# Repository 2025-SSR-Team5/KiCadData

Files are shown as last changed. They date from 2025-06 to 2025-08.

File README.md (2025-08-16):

# KiCadData

## Control Circuit<br>
- A面<br>
<br>

- B面<br>


連結した図
<br>

## Emergency Circuit<br>
動作電圧：7.8V以上（実測値）

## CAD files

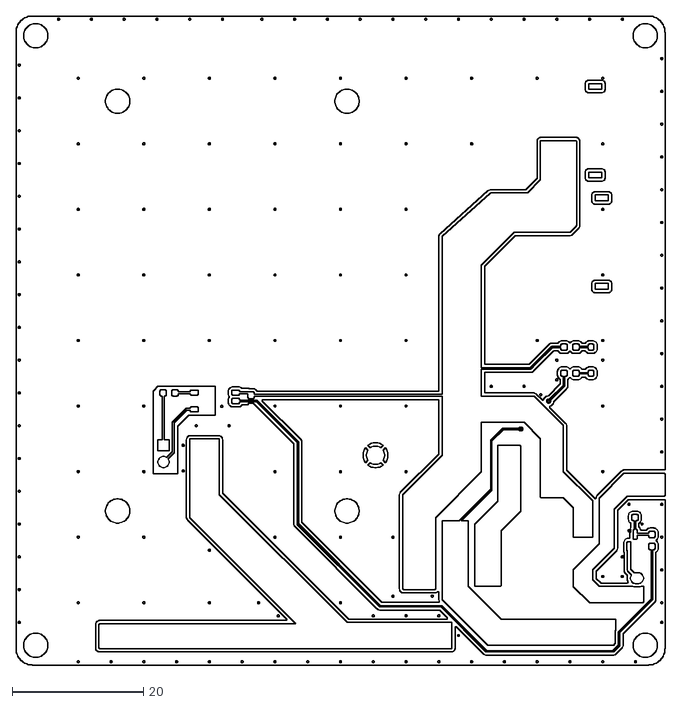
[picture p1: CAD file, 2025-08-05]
maincircuit/Emergency-F_Cu.dxf
99.0 x 99.0

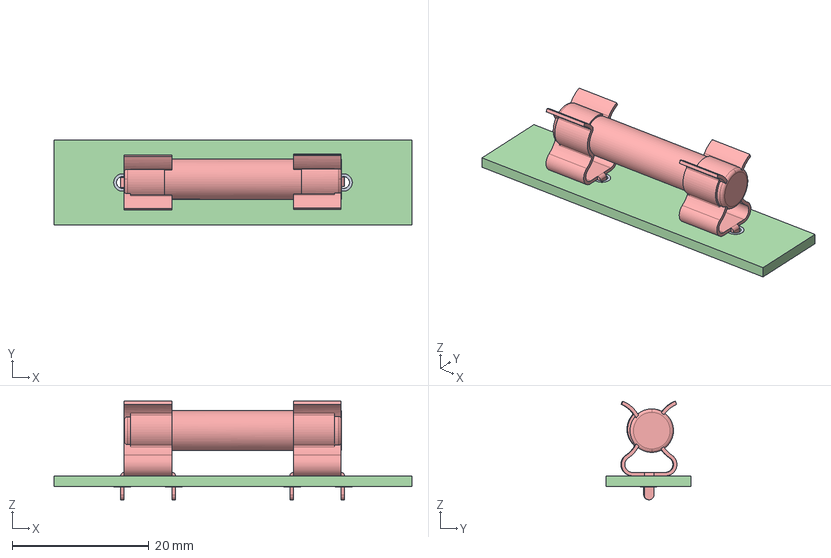
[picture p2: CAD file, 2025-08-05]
maincircuit/FreeCadData/FUC-04.FCStd
52.3 x 12.4 x 14.4 mm
topPads001
btmPads001
TH-Drills001
PCB001
FUC-006

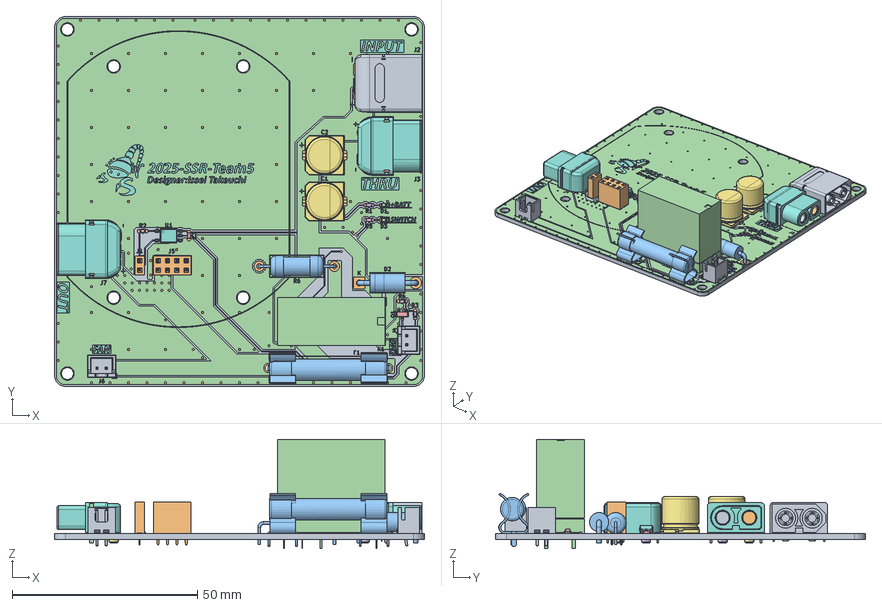
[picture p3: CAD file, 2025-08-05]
maincircuit/FreeCadData/基板外形/Emergency_完成版.FCStd
100.0 x 100.0 x 29.5 mm
Pcb_5d9a
topPads_5d9a
topTracks_5d9a
topZones_5d9a
botPads_5d9a
botTracks_5d9a
botZones_5d9a
topSilks_7ed9
J2_XT60PW-M_b9f98f7f5a08[2]
J1_PinSocket_1x02_P2.54mm_Vertical_96c703c1ea02
F1_FUC-006_d50f9b82165b
XT60PW_F x 2
XT60PW_F001 x 2
XT60PW_F002 x 2
XT60PW_F003 x 2
XT60PW_F004 x 2
XT60PW_F005 x 2
XT60PW_F006 x 2
D2_D_DO-201AD_P15.24mm_Horizontal_769b02e1d70d
D3_LED_0603_1608Metric_7a1c755dfa72 x 2
Q1_SOT-23_4aa83119404f
R1_R_0603_1608Metric_e639d62fb8c0 x 5
C2_CP_Elec_10x10_c9efb6612453 x 2
U1_SO-5-6_4.55x3.7mm_P1.27mm_6e65fe9860de
J4_JST_B2B_XH_A_65221954baed x 2
J5_PinSocket_2x04_P2.54mm_Vertical_8e1d09d268e3
R6_R_Axial_DIN0614_L143mm_D57mm_P2032mm_Horizontal_5dc615bd2039
K1_G2R_1_E_94cef88badf6
C3_C_0603_1608Metric_b537dff13701

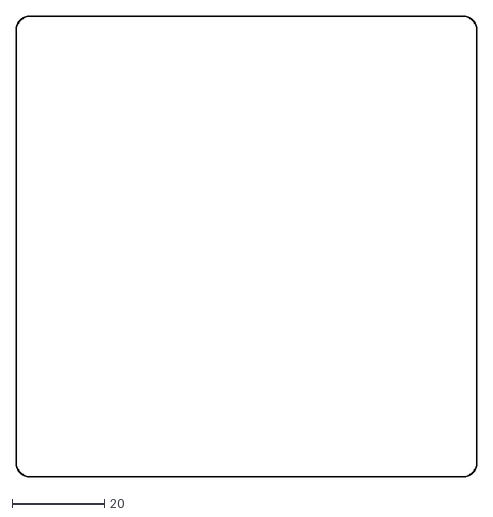
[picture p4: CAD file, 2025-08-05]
maincircuit/Emergency-Edge_Cuts.dxf
100.0 x 100.0

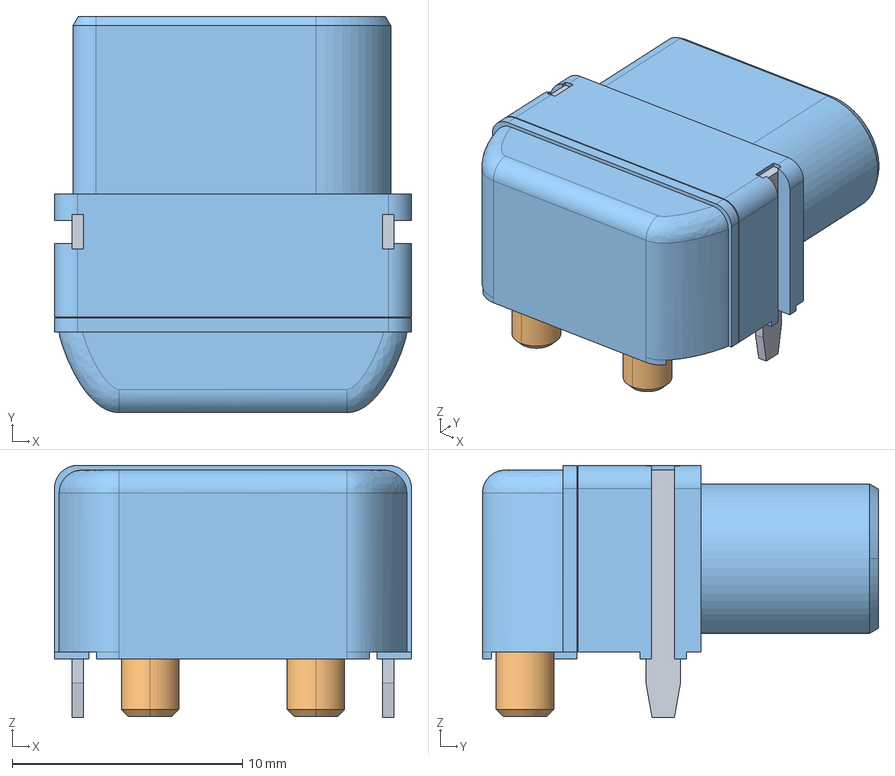
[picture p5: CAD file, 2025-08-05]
maincircuit/FreeCadData/XT60PW_F_cp001.step
15.5 x 17.2 x 10.9 mm

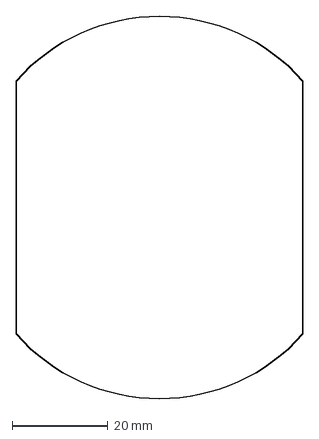
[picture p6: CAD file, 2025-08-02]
maincircuit/FreeCadData/基板外形/ControlCircuit.dxf
60.0 x 80.0 mm

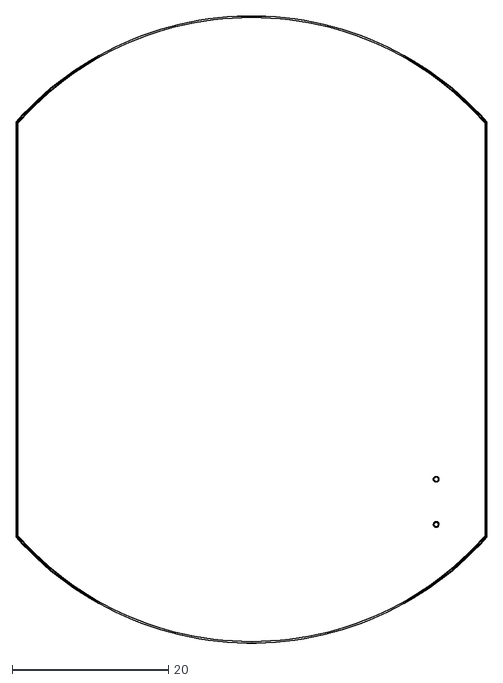
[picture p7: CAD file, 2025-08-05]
maincircuit/ControlCircuit-Edge_Cuts.dxf
60.2 x 80.2

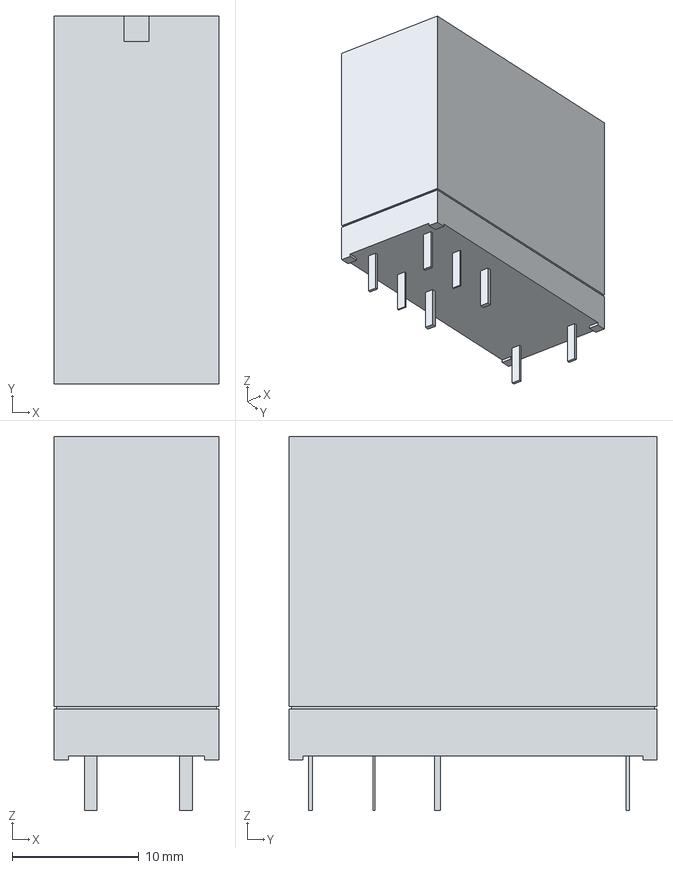
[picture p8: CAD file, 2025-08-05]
maincircuit/FreeCadData/G2R_1_E.step
13.0 x 29.0 x 29.5 mm

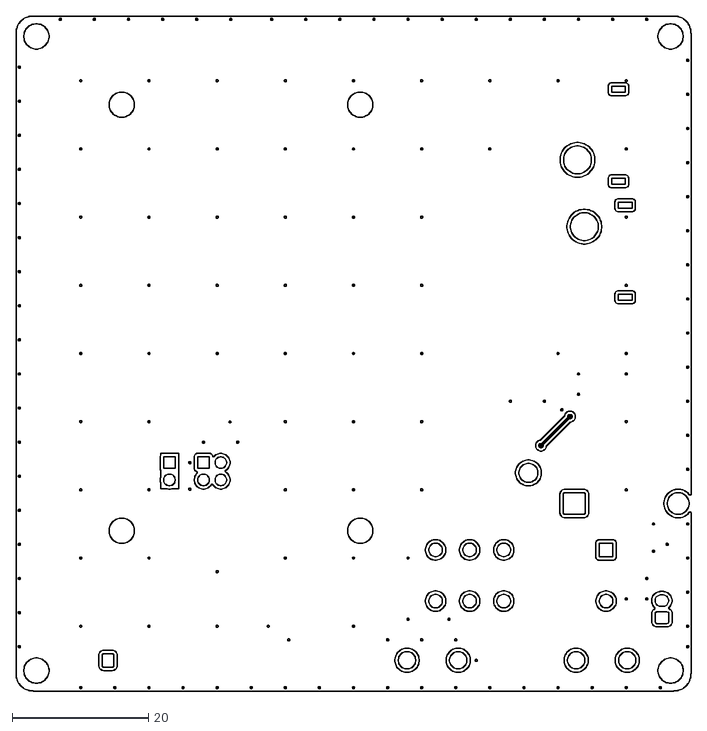
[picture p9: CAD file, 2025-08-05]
maincircuit/Emergency-B_Cu.dxf
99.0 x 99.0

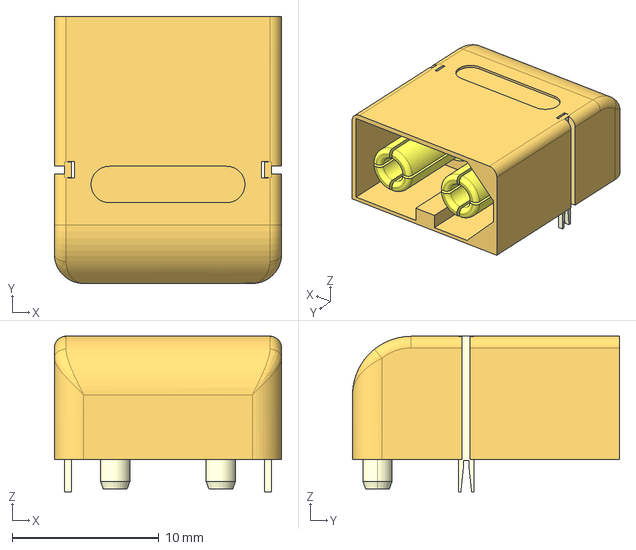
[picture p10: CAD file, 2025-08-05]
maincircuit/FreeCadData/XT60PW-M.step
15.5 x 18.2 x 10.6 mm

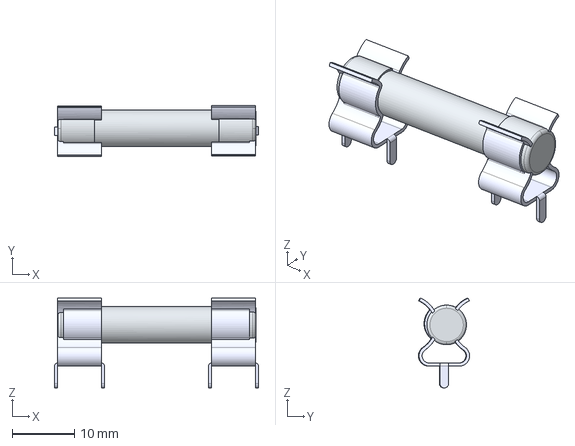
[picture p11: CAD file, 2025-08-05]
maincircuit/FreeCadData/FUC-006.step
32.7 x 8.20 x 14.4 mm

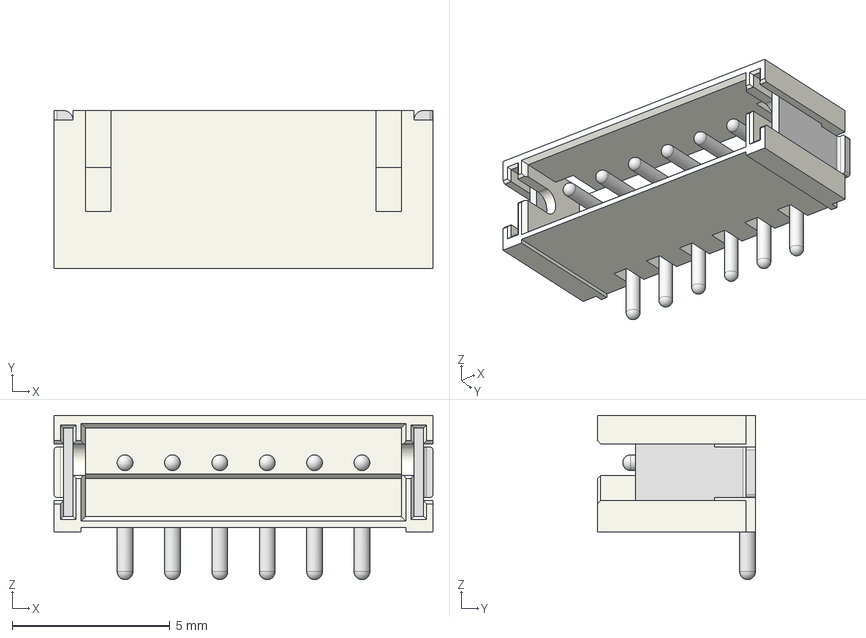
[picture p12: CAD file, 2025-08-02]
maincircuit/FreeCadData/ZH_Connector_SMT_Top.step
12.0 x 5.00 x 5.20 mm

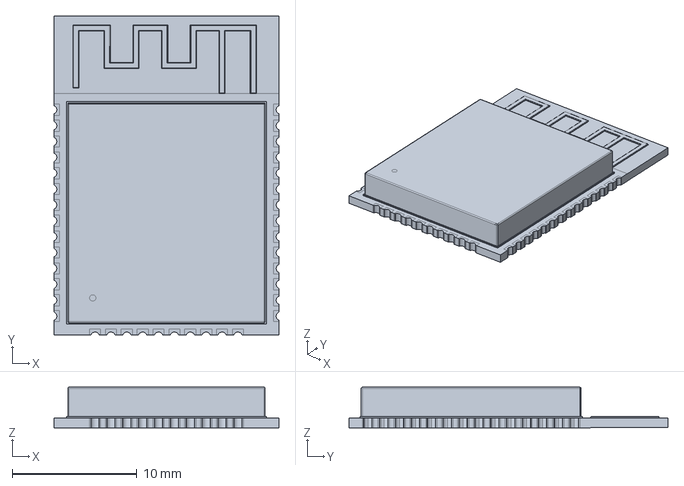
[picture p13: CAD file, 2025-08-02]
maincircuit/FreeCadData/ESP32-WROOM-32.step
18.0 x 25.5 x 3.25 mm

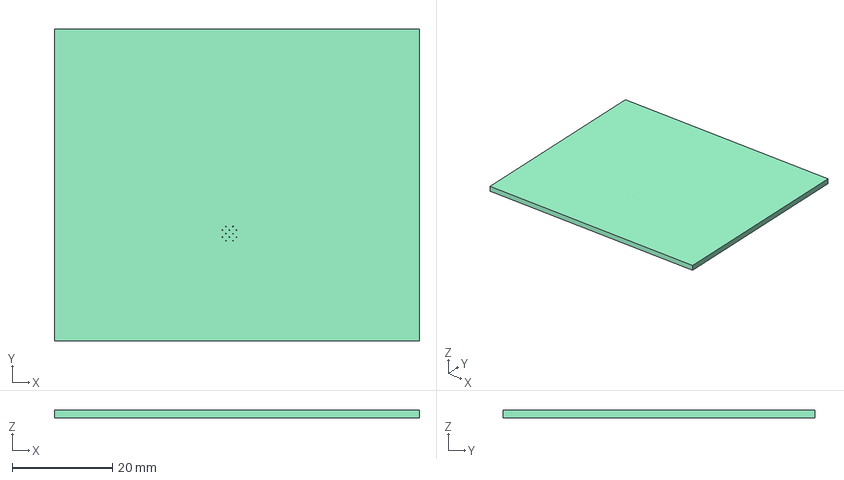
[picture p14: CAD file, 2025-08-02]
maincircuit/FreeCadData/PCB.step
72.8 x 62.3 x 1.58 mm

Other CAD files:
maincircuit/FreeCadData/XT60PW_F.step
maincircuit/FreeCadData/ESP32.FCStd
maincircuit/FreeCadData/MA10EB045.stp
maincircuit/FreeCadData/ZH_B6B.FCStd
maincircuit/ControlCircuit-B_Silkscreen.dxf
maincircuit/ControlCircuit-F_Silkscreen.dxf
maincircuit/Emergency-B_Mask.dxf
maincircuit/Emergency-B_Paste.dxf
maincircuit/Emergency-B_Silkscreen.dxf
maincircuit/Emergency-F_Mask.dxf
maincircuit/Emergency-F_Paste.dxf
maincircuit/Emergency-F_Silkscreen.dxf
maincircuit/FreeCadData/10132797-017100LF.FCStd
maincircuit/FreeCadData/10132797-017100LF.step
maincircuit/FreeCadData/10132798-012100LF.FCStd
maincircuit/FreeCadData/10132798-012100LF_ASM.step
maincircuit/FreeCadData/2SC3325.FCStd
maincircuit/FreeCadData/2SC3325.step
maincircuit/FreeCadData/5077CR-16SMC2-BK-TR019.FCStd
maincircuit/FreeCadData/5077CR-16SMC2-BK-TR019.step
maincircuit/FreeCadData/Fusion001.step
maincircuit/FreeCadData/G2R-1-E.FCStd
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

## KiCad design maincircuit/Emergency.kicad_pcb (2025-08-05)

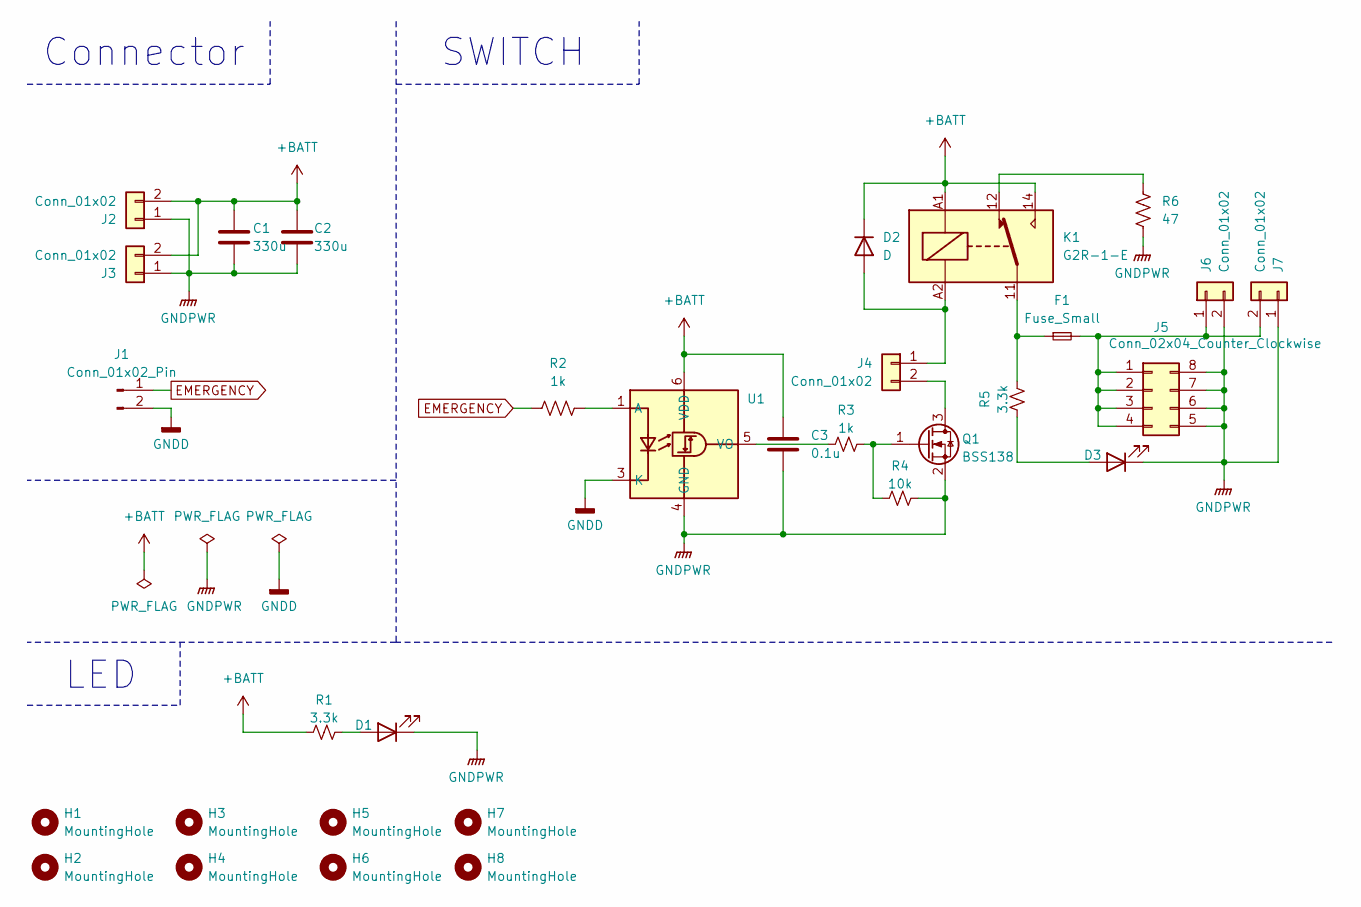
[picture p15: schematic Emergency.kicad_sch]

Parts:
C1, C2: 330u; CP_Elec_10x10
C3: 0.1u; C_0603_1608Metric_Pad1.08x0.95mm_HandSolder
D1, D3: LED; LED_0603_1608Metric
D2: D; D_DO-201AD_P15.24mm_Horizontal
F1: Fuse_Small; FUC-04
H1, H2, H3, H4, H5, H6, H7, H8: MountingHole; MountingHole_3.2mm_M3
J1: Conn_01x02_Pin; PinSocket_1x02_P2.54mm_Vertical
J2: Conn_01x02; AMASS_XT60PW-M_1x02_P7.20mm_Horizontal
J3, J7: Conn_01x02; AMASS_XT60PW-F_1x02_P7.20mm_Horizontal
J4, J6: Conn_01x02; JST_XH_B2B-XH-A_1x02_P2.50mm_Vertical
J5: Conn_02x04_Counter_Clockwise; PinSocket_2x04_P2.54mm_Vertical
K1: G2R-1-E
Q1: BSS138; SOT-23
R1, R5: 3.3k; R_0603_1608Metric_Pad0.98x0.95mm_HandSolder
R2, R3: 1k; R_0603_1608Metric_Pad0.98x0.95mm_HandSolder
R4: 10k; R_0603_1608Metric_Pad0.98x0.95mm_HandSolder
R6: 47; R_Axial_DIN0614_L14.3mm_D5.7mm_P20.32mm_Horizontal
U1: SO-5-6_4.55x3.7mm_P1.27mm

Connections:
+BATT: C1.1, C2.1, C3.1, D2.1 (K), J2.2, J3.2, K1.14, K1.A1, R1.1, U1.6 (VDD)
EMERGENCY: J1.1, R2.1
GNDD: J1.2, U1.3 (K)
GNDPWR: C1.2, C2.2, C3.2, D1.1 (K), D3.1 (K), J2.1, J3.1, J5.5, J5.6, J5.7, J5.8, J6.2, J7.1, Q1.2 (S), R4.2, R6.2, U1.4 (GND)
unnamed: D1.2 (A), R1.2
unnamed: D2.2 (A), J4.1, K1.A2
unnamed: D3.2 (A), R5.1
unnamed: F1.1, K1.11, R5.2
unnamed: J4.2, Q1.3 (D)
unnamed: F1.2, J5.1, J5.2, J5.3, J5.4, J6.1, J7.2
unnamed: K1.12, R6.1
unnamed: Q1.1 (G), R3.2, R4.1
unnamed: R2.2, U1.1 (A)
unnamed: R3.1, U1.5 (VO)

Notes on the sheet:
Connector
SWITCH
LED

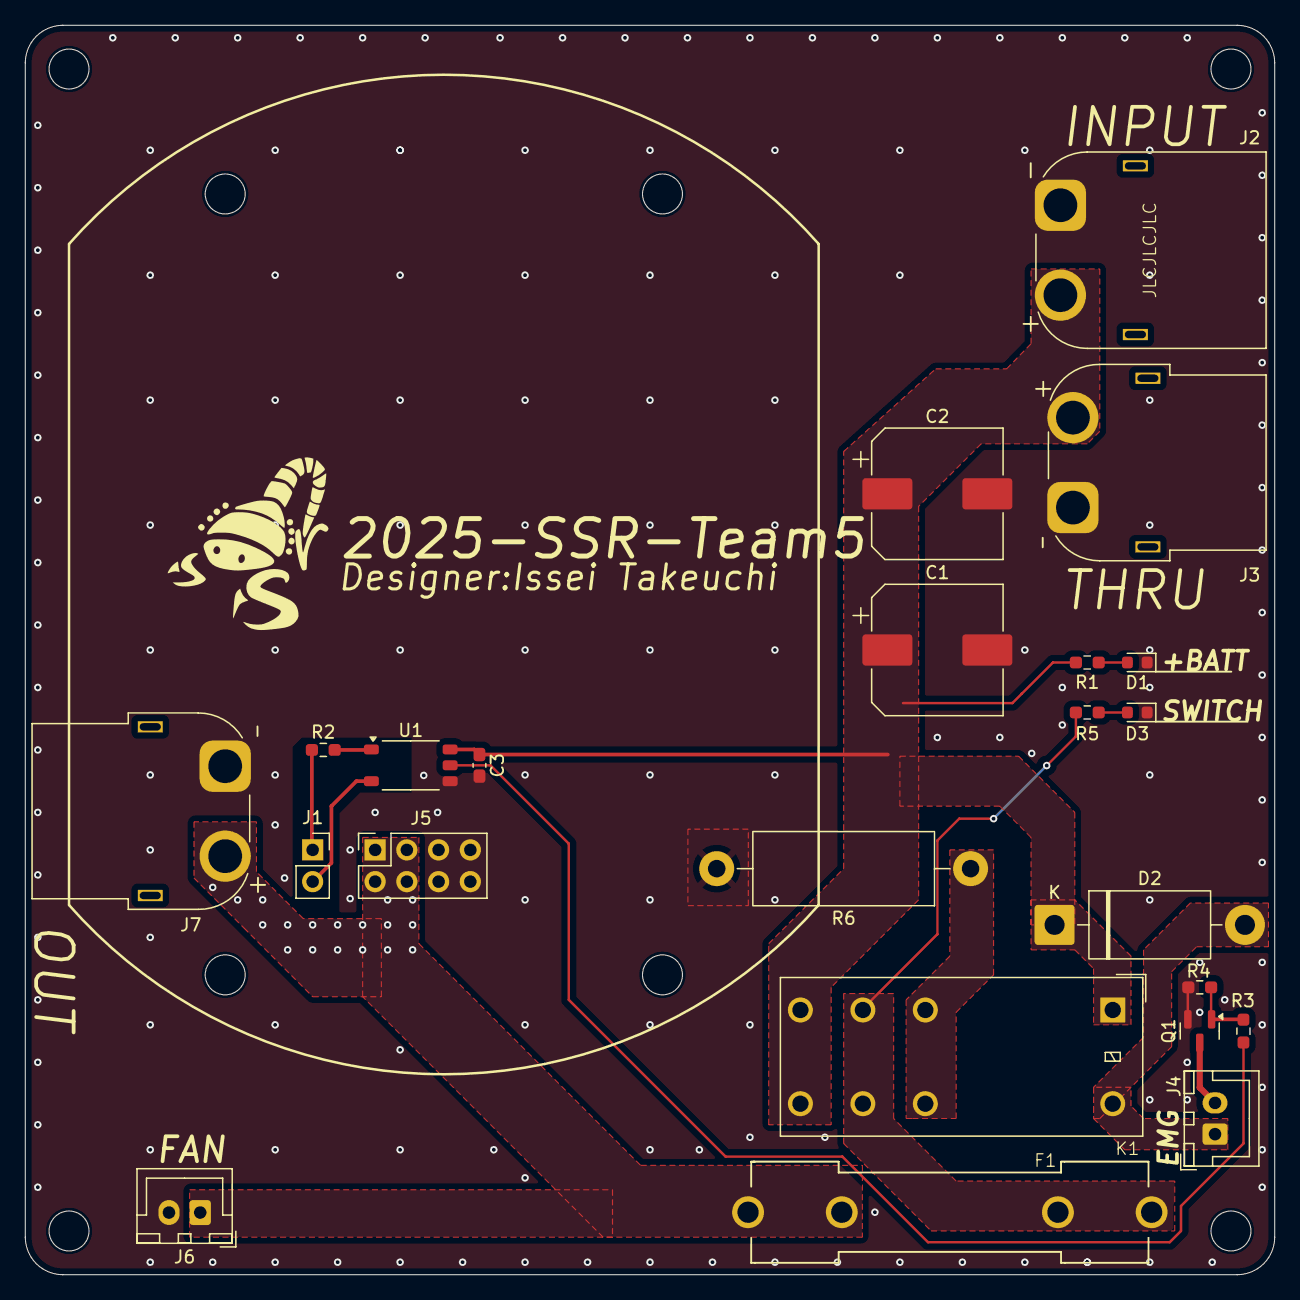
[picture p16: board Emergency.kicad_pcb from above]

Board: 2 copper layers, 100.0 x 100.0 mm, 31 parts (0 on the bottom side), 14 nets.

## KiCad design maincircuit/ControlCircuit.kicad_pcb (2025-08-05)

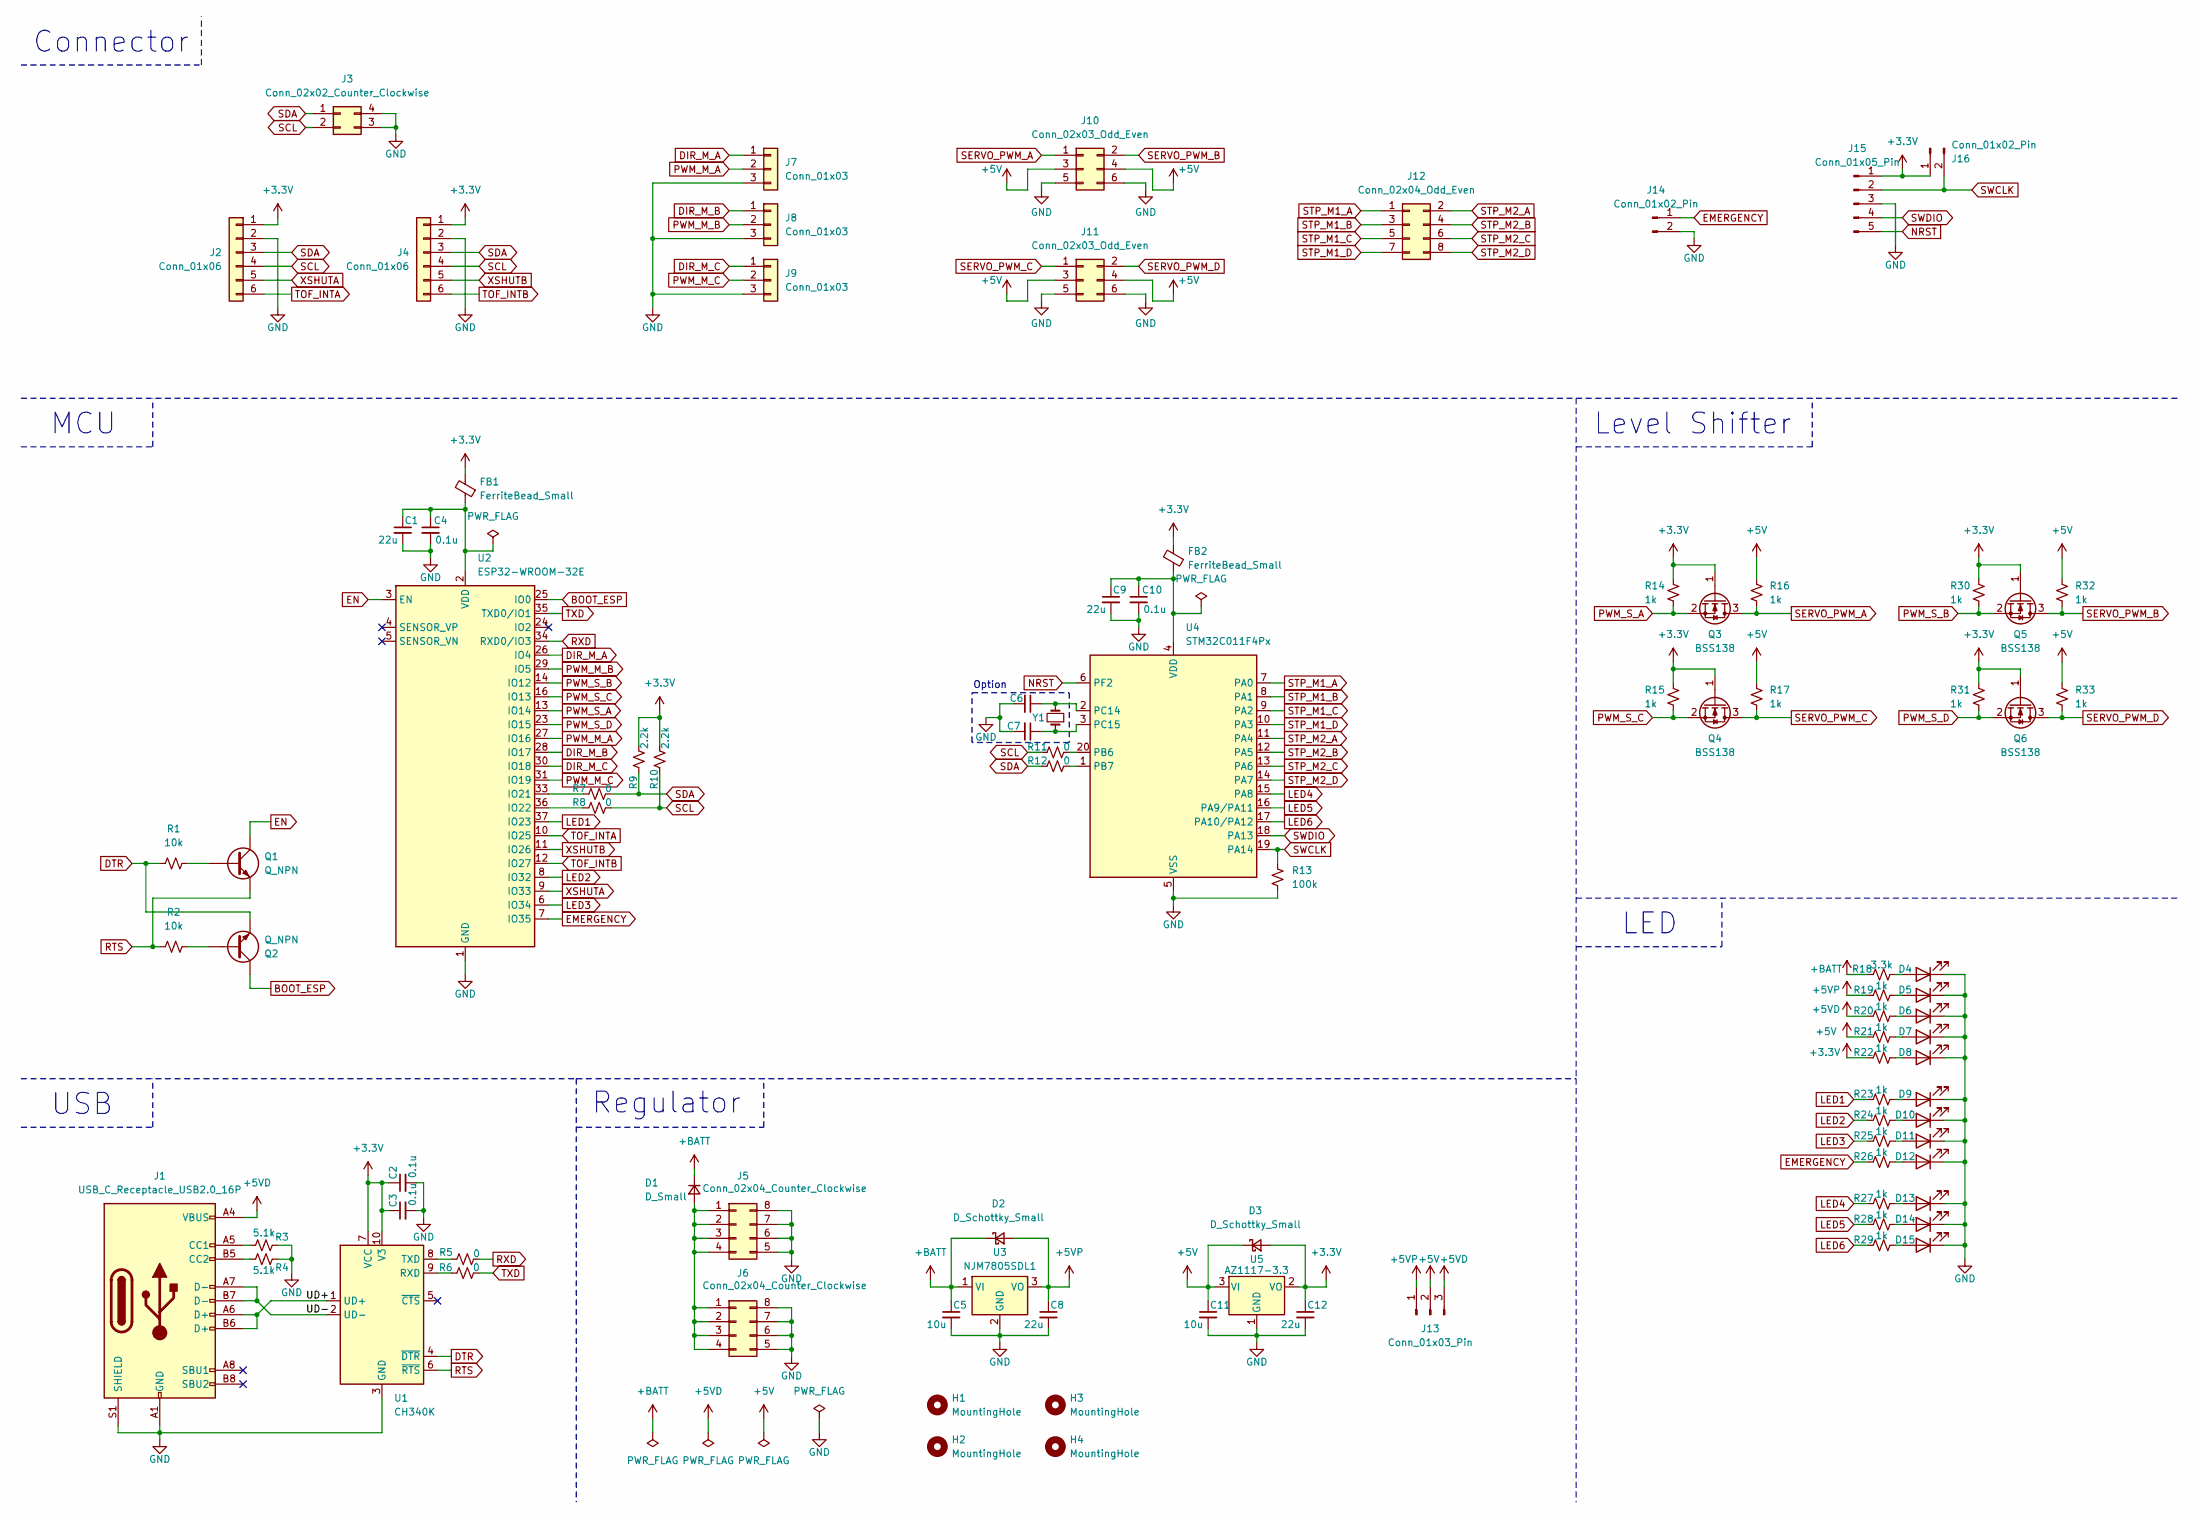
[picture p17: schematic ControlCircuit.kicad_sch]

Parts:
C1, C8, C9, C12: 22u; C_0603_1608Metric_Pad1.08x0.95mm_HandSolder
C2, C3, C4, C10: 0.1u; C_0603_1608Metric_Pad1.08x0.95mm_HandSolder
C5, C11: 10u; C_0603_1608Metric_Pad1.08x0.95mm_HandSolder
C6, C7: C_Small; C_0603_1608Metric_Pad1.08x0.95mm_HandSolder
D1: D_Small; Vishay_SMPA
D2, D3: D_Schottky_Small; Nexperia_CFP3_SOD-123W
D4, D5, D6, D7, D8, D9, D10, D11, D12, D13, D14, D15: LED; LED_0603_1608Metric
FB1, FB2: FerriteBead_Small; L_0603_1608Metric_Pad1.05x0.95mm_HandSolder
H1, H2, H3, H4: MountingHole; MountingHole_3.2mm_M3
J1: USB_C_Receptacle_USB2.0_16P; 5077CR-16-SMC2-BK-TR
J2, J4: Conn_01x06; JST_ZH_B6B-ZR_1x06_P1.50mm_Vertical
J3: Conn_02x02_Counter_Clockwise; PinSocket_2x02_P2.54mm_Vertical
J5: Conn_02x04_Counter_Clockwise; PinHeader_2x04_P2.54mm_Vertical
J6: Conn_02x04_Counter_Clockwise; PinSocket_2x04_P2.54mm_Vertical
J7, J8, J9: Conn_01x03; JST_XH_S3B-XH-A_1x03_P2.50mm_Horizontal
J10, J11: Conn_02x03_Odd_Even; PinHeader_2x03_P2.54mm_Horizontal
J12: Conn_02x04_Odd_Even; PinHeader_2x04_P2.54mm_Horizontal
J13: Conn_01x03_Pin; PinHeader_1x03_P2.54mm_Horizontal
J14: Conn_01x02_Pin; PinHeader_1x02_P2.54mm_Vertical
J15: Conn_01x05_Pin; PinHeader_1x05_P2.54mm_Horizontal
J16: Conn_01x02_Pin; PinHeader_1x02_P2.54mm_Horizontal
Q1, Q2: Q_NPN; SOT-23
Q3, Q4, Q5, Q6: BSS138; SOT-23
R1, R2: 10k; R_0603_1608Metric_Pad0.98x0.95mm_HandSolder
R3, R4: 5.1k; R_0603_1608Metric_Pad0.98x0.95mm_HandSolder
R5, R6, R7, R8, R11, R12: 0; R_0603_1608Metric_Pad0.98x0.95mm_HandSolder
R9, R10: 2.2k; R_0603_1608Metric_Pad0.98x0.95mm_HandSolder
R13: 100k; R_0603_1608Metric_Pad0.98x0.95mm_HandSolder
R14, R15, R16, R17, R19, R20, R21, R22, R23, R24, R25, R26, R27, R28, R29, R30, R31, R32, R33: 1k; R_0603_1608Metric_Pad0.98x0.95mm_HandSolder
R18: 3.3k; R_0603_1608Metric_Pad0.98x0.95mm_HandSolder
U1: CH340K; SSOP-10-1EP_3.9x4.9mm_P1mm_EP2.1x3.3mm
U2: ESP32-WROOM-32E; ESP32-WROOM-32D
U3: NJM7805SDL1; TO-252-2
U4: STM32C011F4Px; TSSOP-20_4.4x6.5mm_P0.65mm
U5: AZ1117-3.3; SOT-223
Y1: Crystal_Small; Crystal_SMD_3215-2Pin_3.2x1.5mm

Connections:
+3.3V: C2.1, C3.1, C12.1, D3.2 (A), FB1.2, FB2.2, J4.1, J15.1, J16.1, Q3.1 (G), Q4.1 (G), Q5.1 (G), Q6.1 (G), R9.1, R10.1, R14.1, R15.1, R22.1, R30.1, R31.1, U1.7 (VCC), U1.10 (V3), U5.2 (VO), U5.4 (VO2); also elsewhere on the board
+5V: C11.1, D3.1 (K), J10.3, J10.4, J11.3, J11.4, J13.2, R16.1, R17.1, R21.1, R32.1, R33.1, U5.3 (VI)
+5VD: J1.A4 (VBUS), J1.A9 (VBUS), J1.B4 (VBUS), J1.B9 (VBUS), J13.3, R20.1
+5VP: C8.1, D2.2 (A), J13.1, R19.1, U3.3 (VO)
+BATT: C5.1, D1.1 (K), D2.1 (K), R18.1, U3.1 (VI)
/UD+: J1.A6 (D+), J1.B6 (D+), U1.1 (UD+)
/UD-: J1.A7 (D-), J1.B7 (D-), U1.2 (UD-)
BOOT_ESP: Q2.3 (C), U2.25 (IO0)
DIR_M_A: J7.1, U2.26 (IO4)
DIR_M_B: J8.1, U2.28 (IO17)
DIR_M_C: J9.1, U2.30 (IO18)
DTR: Q2.2 (E), R1.1, U1.4 (~DTR)
EMERGENCY: J14.1, R26.1, U2.7 (IO35)
EN: Q1.3 (C), U2.3 (EN)
GND: C1.2, C2.2, C3.2, C4.2, C5.2, C6.2, C7.2, C8.2, C9.2, C10.2, C11.2, C12.2, D4.1 (K), D5.1 (K), D6.1 (K), D7.1 (K), D8.1 (K), D9.1 (K), D10.1 (K), D11.1 (K), D12.1 (K), D13.1 (K), D14.1 (K), D15.1 (K), J1.A1 (GND), J1.A12 (GND), J1.B1 (GND), J1.B12 (GND), J1.S1 (SHIELD), J3.3, J3.4, J4.2, J5.5, J5.6, J5.7, J5.8, J6.5, J6.6, J6.7, J6.8, J7.3, J8.3, J9.3, J10.5, J10.6, J11.5, J11.6, J14.2, J15.3, R3.2, R4.2, R13.2, U1.3 (GND), U1.11 (GND), U2.1 (GND), U2.15 (GND), U2.38 (GND), U2.39 (GND), U3.2 (GND), U4.5 (VSS), U5.1 (GND); also elsewhere on the board
LED1: R23.1, U2.37 (IO23)
LED2: R24.1, U2.8 (IO32)
LED3: R25.1, U2.6 (IO34)
LED4: R27.1, U4.15 (PA8)
LED5: R28.1, U4.16 (PA9/PA11)
LED6: R29.1, U4.17 (PA10/PA12)
NRST: J15.5, U4.6 (PF2)
unnamed: D1.2 (A), J5.1, J5.2, J5.3, J5.4, J6.1, J6.2, J6.3, J6.4
unnamed: D4.2 (A), R18.2
unnamed: D5.2 (A), R19.2
unnamed: D6.2 (A), R20.2
unnamed: D7.2 (A), R21.2
unnamed: D8.2 (A), R22.2
unnamed: D9.2 (A), R23.2
unnamed: D10.2 (A), R24.2
unnamed: D11.2 (A), R25.2
unnamed: D12.2 (A), R26.2
unnamed: D13.2 (A), R27.2
unnamed: D14.2 (A), R28.2
unnamed: D15.2 (A), R29.2
unnamed: J1.A5 (CC1), R3.1
unnamed: J1.B5 (CC2), R4.1
unnamed: Q1.1 (B), R1.2
unnamed: Q2.1 (B), R2.2
unnamed: R6.1, U1.9 (RXD)
unnamed: R5.1, U1.8 (TXD)
unnamed: R7.1, U2.33 (IO21)
unnamed: R8.1, U2.36 (IO22)
unnamed: C1.1, C4.1, FB1.1, U2.2 (VDD)
unnamed: R11.2, U4.20 (PB6)
unnamed: R12.2, U4.1 (PB7)
unnamed: C6.1, U4.2 (PC14), Y1.2
unnamed: C7.1, U4.3 (PC15), Y1.1
unnamed: C9.1, C10.1, FB2.1, U4.4 (VDD)
PWM_M_A: J7.2, U2.27 (IO16)
PWM_M_B: J8.2, U2.29 (IO5)
PWM_M_C: J9.2, U2.31 (IO19)
PWM_S_A: Q3.2 (S), R14.2, U2.13 (IO14)
PWM_S_B: Q5.2 (S), R30.2, U2.14 (IO12)
PWM_S_C: Q4.2 (S), R15.2, U2.16 (IO13)
PWM_S_D: Q6.2 (S), R31.2, U2.23 (IO15)
RTS: Q1.2 (E), R2.1, U1.6 (~RTS)
RXD: R5.2, U2.34 (RXD0/IO3)
SCL: J3.2, J4.4, R8.2, R10.2, R11.1; also elsewhere on the board
SDA: J3.1, J4.3, R7.2, R9.2, R12.1; also elsewhere on the board
SERVO_PWM_A: J10.1, Q3.3 (D), R16.2
SERVO_PWM_B: J10.2, Q5.3 (D), R32.2
SERVO_PWM_C: J11.1, Q4.3 (D), R17.2
SERVO_PWM_D: J11.2, Q6.3 (D), R33.2
STP_M1_A: J12.1, U4.7 (PA0)
STP_M1_B: J12.3, U4.8 (PA1)
STP_M1_C: J12.5, U4.9 (PA2)
STP_M1_D: J12.7, U4.10 (PA3)
STP_M2_A: J12.2, U4.11 (PA4)
STP_M2_B: J12.4, U4.12 (PA5)
STP_M2_C: J12.6, U4.13 (PA6)
STP_M2_D: J12.8, U4.14 (PA7)
SWCLK: J15.2, J16.2, R13.1, U4.19 (PA14)
SWDIO: J15.4, U4.18 (PA13)
TOF_INTA: J2.6, U2.10 (IO25); also elsewhere on the board
TOF_INTB: J4.6, U2.12 (IO27)
TXD: R6.2, U2.35 (TXD0/IO1)
XSHUTA: J2.5, U2.9 (IO33); also elsewhere on the board
XSHUTB: J4.5, U2.11 (IO26)

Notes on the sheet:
USB
Regulator
MCU
LED
Level Shifter
Option
Connector

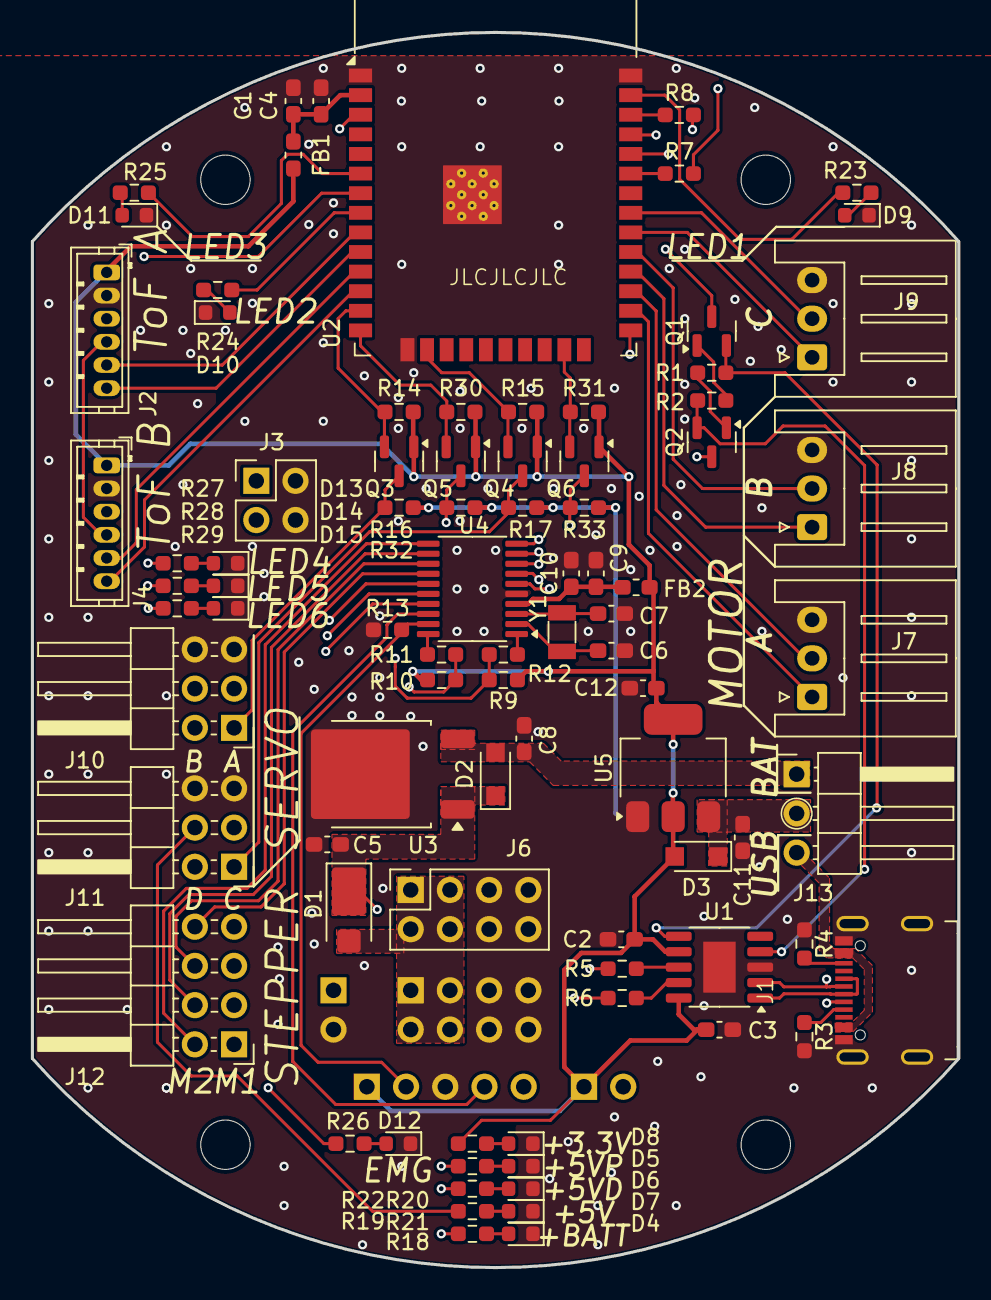
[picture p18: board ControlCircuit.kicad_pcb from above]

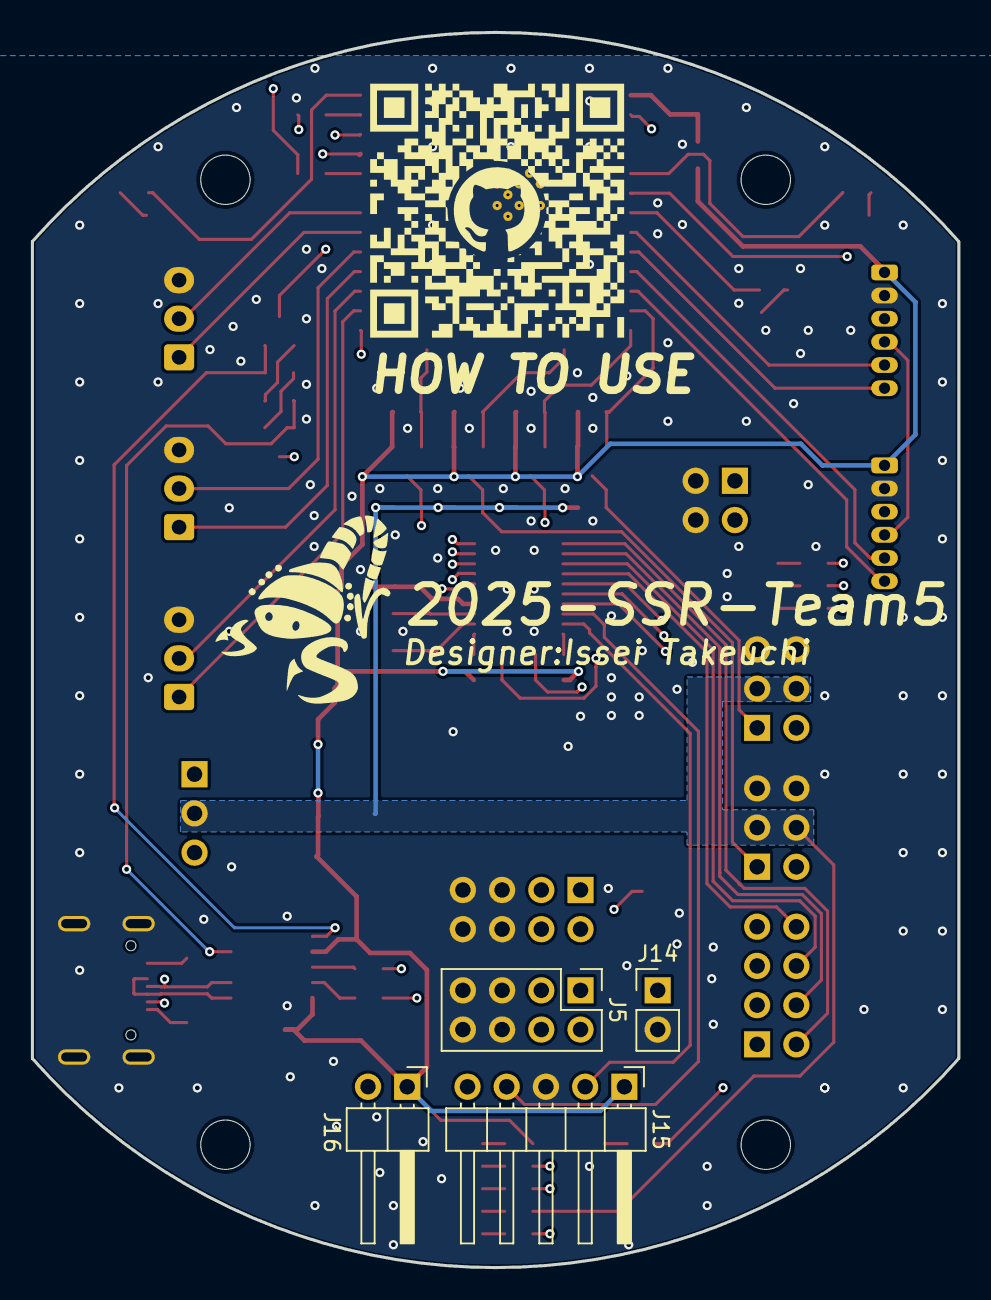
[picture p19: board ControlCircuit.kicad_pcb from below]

Board: 4 copper layers, 60.0 x 80.0 mm, 94 parts (4 on the bottom side), 79 nets.

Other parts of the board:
ToF A: Conn_01x06; JST_ZH_B6B-ZR_1x06_P1.50mm_Vertical

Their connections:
+3.3V: ToF A.1; also elsewhere on the board
GND: ToF A.2; also elsewhere on the board
SCL: ToF A.4; also elsewhere on the board
SDA: ToF A.3; also elsewhere on the board
TOF_INTA: ToF A.6; also elsewhere on the board
XSHUTA: ToF A.5; also elsewhere on the board

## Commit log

2025-06-30 add: initial commit/非常停止回路関係の追加
    [ControlCircuit.kicad_sch, Emergency.kicad_sch, maincircuit.kicad_pcb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]
2025-07-07 add: ESP32-WROOM-32E-MINIのライブラリの追加
    [ESP32.FCStd]
2025-07-13 add: 07/13進捗分(主にcontrol回路)
    [2SC3325.FCStd, 2SC3325.step, 5077CR-16SMC2-BK-TR019.FCStd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]
2025-08-02 [add]ControlCircuit完成
    [10132797-017100LF.FCStd, 10132797-017100LF.step, 10132798-012100LF.FCStd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]
2025-08-05 add: ver1.0の基板データの完成
    [ControlCircuit-B_Silkscreen.dxf, ControlCircuit-Edge_Cuts.dxf, ControlCircuit-F_Silkscreen.dxf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]
